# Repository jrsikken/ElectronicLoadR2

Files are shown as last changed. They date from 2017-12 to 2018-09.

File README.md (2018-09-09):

# Hardware of Jasper's Electronic Load R2
This is a Arduino compatible Electronic Load. It is intended for testing DC power supplies, solar panels and batteries. 
I am selling on Tindie https://www.tindie.com/products/jaspersikken/jaspers-electronic-load-r2/
Technical details are also found there.


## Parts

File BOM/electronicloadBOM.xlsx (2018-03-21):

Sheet: electronicloadBOM
Qty | Value | Package | Parts | Description | TOLERANCE | MF | MPN | Ebay
3 | 0.3R | R2512 | R12, R14, R15 | Resistor | 1% |  |  | http://www.ebay.com/itm/100PCS-2512-6432-1W-0-3-ohm-R300-0-3R-1-SMD-resistors/291647639892
1 | 100k | R0603 | R11 | RESISTOR, European symbol | 1% |  |  | http://www.ebay.com/itm/200Pcs-0603-SMD-Resistor-Resistors-1K-910K-Ohm-Ω-1-High-Quality-Free-Shipping/192101507976
3 | 100n | C0603 | C2, C4, C7 | CAPACITOR, European symbol | 10% |  |  | http://www.ebay.com/itm/100PCS-0603-1608-100n-100nF-104K-10-50V-X7R-SMD-capacitor-MLCC/391284797144
3 | 150R | R0603 | R3, R4, R13 | RESISTOR, European symbol | 1% |  |  | http://www.ebay.com/itm/200PCS-150R-150-ohm-Ω-1-1-10W-SMD-Chip-Resistor-0603-1-6mm-0-8mm/231949532343
1 | 1k8 | R0603 | R1 | RESISTOR, European symbol | 1% |  |  | http://www.ebay.com/itm/100pcs-0603-SMD-Resistor-1-8K-ohm-1K8-Tol-5-RoHS-1-10W/291817476969
4 | 1u | C0603 | C1, C3, C5, C6 | CAPACITOR, European symbol | 10% |  |  | http://www.ebay.com/itm/100PCS-1uF-105K-10-16V-X7R-0603-1608-SMD-capacitor-MLCC-1-6mm-0-8mm/232352831873
4 | 20k | R0603 | R2, R5, R8, R10 | RESISTOR, European symbol | 1% |  |  | http://www.ebay.com/itm/200Pcs-0603-SMD-Resistor-Resistors-1K-910K-Ohm-Ω-1-High-Quality-Free-Shipping/192101507976
1 | 22n | C0603 | C8 | CAPACITOR, European symbol | 10% |  |  | http://www.ebay.com/itm/100PCS-22nF-223-10-50V-X7R-0603-1608-SMD-capacitor-MLCC/232244234398
1 | 2k2 | R0603 | R9 | RESISTOR, European symbol | 1% |  |  | http://www.ebay.com/itm/200Pcs-0603-SMD-Resistor-Resistors-1K-910K-Ohm-Ω-1-High-Quality-Free-Shipping/192101507976
3 | 3k6 | R0603 | R6, R7, R16 | RESISTOR, European symbol | 1% |  |  | http://www.ebay.com/itm/200Pcs-0603-SMD-Resistor-Resistors-1K-910K-Ohm-Ω-1-High-Quality-Free-Shipping/192101507976
1 | MCP6074-E/SL | SO14 | U2 | Op Amp |  | Microchip | MCP6074-E/SL
1 | ARDUINO_BLUEPILL | ARDUINO_BLUEPILL | U1 | PCB assembly |  |  |  | http://www.ebay.com/itm/10PCS-STM32F103C8T6-ARM-STM32-Minimum-System-Development-Board-Module-Arduino/171907093814
1 | KF128-2P | KF128-2P | X1 | KF128-2P (5.08 mm) TERMINAL BLOCK |  |  |  | http://www.ebay.com/itm/20pcs-2Pin-Plug-in-Terminal-Block-DG128-Screw-KF128-2P-Pitch-5-08MM-300V-10A/391527936166
1 | BTS133BKSA1 | TO220BV | Q1 | Smart low side power switch |  | Infineon | BTS133BKSA1 | There's are fake ones on ebay. Please buy from Digikey, Mouser, Farnell etc.
1 | AK-122 | SK129-HOLE | KK1 | Aluminum Heatsink Ak-122 H=45mm 42x25x45mm Color=Natural TO-TO-220 |  |  |  | http://www.ebay.com/itm/20pc-Aluminum-Heatsink-Ak-122-H-45mm-Size-42x25x45mm-Color-Natural-TO-3P-TO-220/131284780674
1 | 530002B02500G | SK129-HOLE | KK1-alternative | Aluminum Heatsink H=63.5mm 42x25x63mm Black TO-TO-220 |  | AAVID THERMALLOY | 530002B02500G | http://nl.farnell.com/aavid-thermalloy/530002b02500g/heat-sink-2-6k-w-to-220/dp/2295719
2 | 20p female header |  |  | 2.54mm Pitch 1X20 Pin Female Single Row Straight Header Connector |  |  |  | http://www.ebay.com/itm/20pcs-2-54mm-Pitch-1X-20-Pin-Female-Single-Row-Straight-Header-Connector-PCB-DIY/132035408776
4 | rubber feet | 8 x 2.5 mm |  | Adhesive Silicone Feet Bumpers |  |  |  | http://www.ebay.com/itm/100PCS-Self-Adhesive-Rubber-Feet-Clear-Semicircle-Bumpers-Door-Buffer-Pad/361356150996
1 | heat sink mounting kit |  |  | TO-220 Heatsink Mounting Insulator Kit |  |  |  | http://www.ebay.com/itm/20-sets-TO-220-Heatsink-Mounting-Insulator-Kits/190888986454
1 | CE sticker |  |  | CE Adhesive Sticker |  |  |  | http://www.ebay.com/itm/3-Sheets-CE-Certificated-Label-Stickers-Adhesive-Sticker-Markers-Home-Appliance/172533333629
1 | PCB R2 |  |  | PCB Jasper's Electronic Load R2

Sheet: Revision
Revision | Changes
2.00 | The first released version
2.01 | Changed C5, C7, C6
2.02 | Replaced opamp LMV324 with MCP6004-I/SL
2.03 | Replaced mosfet with BTS133BKSA1
2.1 | Replaced opamp MCP4006 with MCP6074-E/SL
2.2 | Added option for 31W heat sink

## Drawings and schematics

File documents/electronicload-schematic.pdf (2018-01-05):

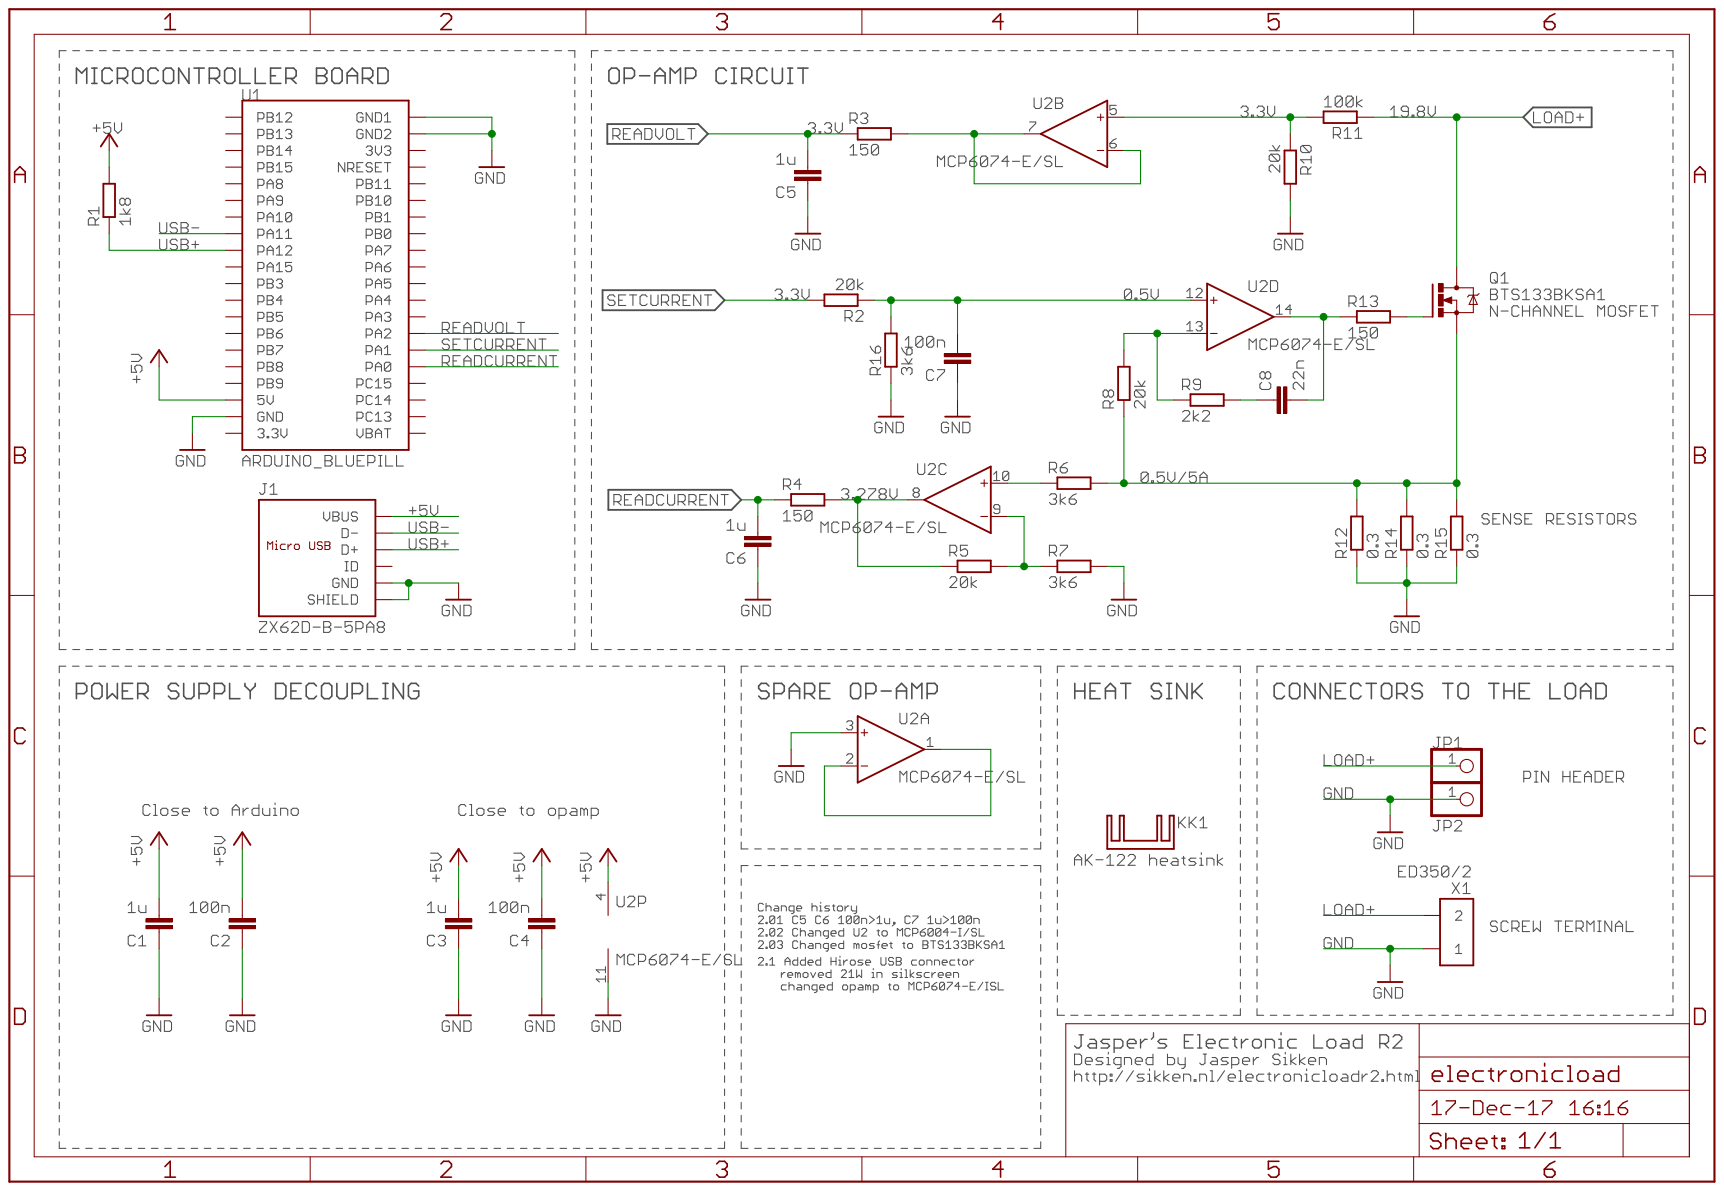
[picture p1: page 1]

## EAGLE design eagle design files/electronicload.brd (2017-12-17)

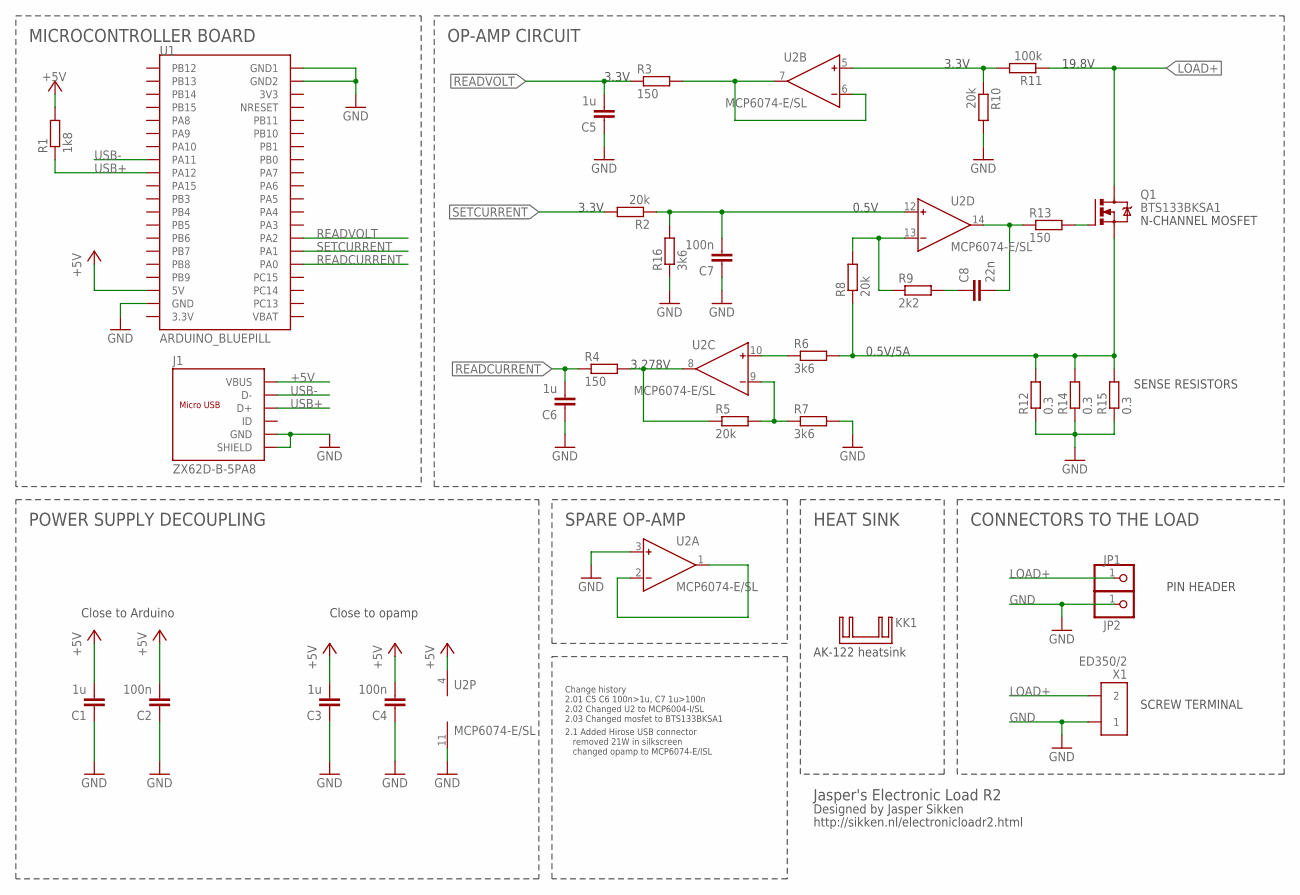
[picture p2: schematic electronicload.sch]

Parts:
C1, C3: 1u; C0603K; TOLERANCE 10%; VOLTAGE 16V; DIGIKEY 311-1444-1-ND
C2, C4: 100n; C0603K; TOLERANCE 10%; VOLTAGE 50V; DIGIKEY 445-7456-1-ND
C5, C6: 1u; C0603K; TOLERANCE 10%; VOLTAGE 50V; DIGIKEY 445-7456-1-ND
C7: 100n; C0603K; TOLERANCE 10%; VOLTAGE 50V; DIGIKEY 445-12511-1-ND
C8: 22n; C0603K; TOLERANCE 10%; VOLTAGE 25V; DIGIKEY 445-12490-1-ND
J1: ZX62D-B-5PA8; MICRO-USB5+6P-SMD-0.65-AB
JP1, JP2: PINHD-1X1; 1X01
KK1: SK129; SK129-HOLE
Q1: BTS133BKSA1; TO220BV; DIGIKEY BTS133BKSA1-ND
R1: 1k8; R0603; DIGIKEY RMCF0603JT18K0CT-ND
R2, R8: 20k; R0603; DIGIKEY RMCF0603JT18K0CT-ND
R3, R4, R13: 150; R0603; DIGIKEY RMCF0603JT150RCT-ND
R5: 20k; R0603; DIGIKEY RMCF0603JT180KCT-ND
R6, R7: 3k6; R0603; DIGIKEY RMCF0603JT20K0CT-ND
R9: 2k2; R0603; DIGIKEY RMCF0603JT2K20CT-ND
R10: 20k; R0603; DIGIKEY RMCF0603JT20K0CT-ND
R11: 100k; R0603; DIGIKEY RMCF0603JT100KCT-ND
R12, R14, R15: 0.3; R2512
R16: 3k6; R0603; DIGIKEY RMCF0603JT18K0CT-ND
U1: ARDUINO_BLUEPILL
U2: MCP6074-E/SL; SO14
X1: ED350/2

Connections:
+5V: C1.2, C2.2, C3.2, C4.2, J1.1 (VBUS), R1.2, U1.P$37 (5V), U2.4 (V+)
GATE: Q1.G, R13.2
GND: C1.1, C2.1, C3.1, C4.1, C5.1, C6.1, C7.1, J1.5 (GND), J1.P1 (SHIELD), J1.P2 (SHIELD), J1.P3 (SHIELD), J1.P4 (SHIELD), J1.P5 (SHIELD), J1.P6 (SHIELD), JP2.1, R7.2, R10.2, R12.1, R14.1, R15.1, R16.1, U1.P$18 (GND2), U1.P$19 (GND1), U1.P$38 (GND), U2.3 (IN+), U2.11 (V-), X1.P$1 (1)
LOAD+: JP1.1, Q1.D, R11.1, X1.P$2 (2)
unnamed: C8.2, R13.1, U2.14 (OUT)
unnamed: R3.2, U2.6 (IN-), U2.7 (OUT)
unnamed: R6.1, U2.10 (IN+)
unnamed: R8.2, R9.1, U2.13 (IN-)
unnamed: R10.1, R11.2, U2.5 (IN+)
unnamed: C7.2, R2.1, R16.2, U2.12 (IN+)
unnamed: R5.2, R7.1, U2.9 (IN-)
unnamed: R4.2, R5.1, U2.8 (OUT)
unnamed: C8.1, R9.2
unnamed: U2.1 (OUT), U2.2 (IN-)
READCURRENT: C6.2, R4.1, U1.P$4 (PA0)
READVOLT: C5.2, R3.1, U1.P$6 (PA2)
SENSE: Q1.S, R6.2, R8.1, R12.2, R14.2, R15.2
SETCURRENT: R2.2, U1.P$5 (PA1)
USB+: J1.3 (D+), R1.1, U1.P$28 (PA12)
USB-: J1.2 (D-), U1.P$27 (PA11)

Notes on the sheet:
POWER SUPPLY DECOUPLING
PIN HEADER
SCREW TERMINAL
SENSE RESISTORS
N-CHANNEL MOSFET
3.3V
19.8V
0.5V
0.5V/5A
3.278V
Designed by Jasper Sikken
http://sikken.nl/electronicloadr2.html
Close to Arduino
Close to opamp
HEAT SINK
SPARE OP-AMP
CONNECTORS TO THE LOAD
MICROCONTROLLER BOARD
OP-AMP CIRCUIT
AK-122 heatsink
Jasper's Electronic Load R2
Change history 2.01 C5 C6 100n>1u, C7 1u>100n 2.02 Changed U2 to MCP6004-I/SL 2.03 Changed mosfet to BTS133BKSA1
2.1 Added Hirose USB connector removed 21W in silkscreen changed opamp to MCP6074-E/ISL

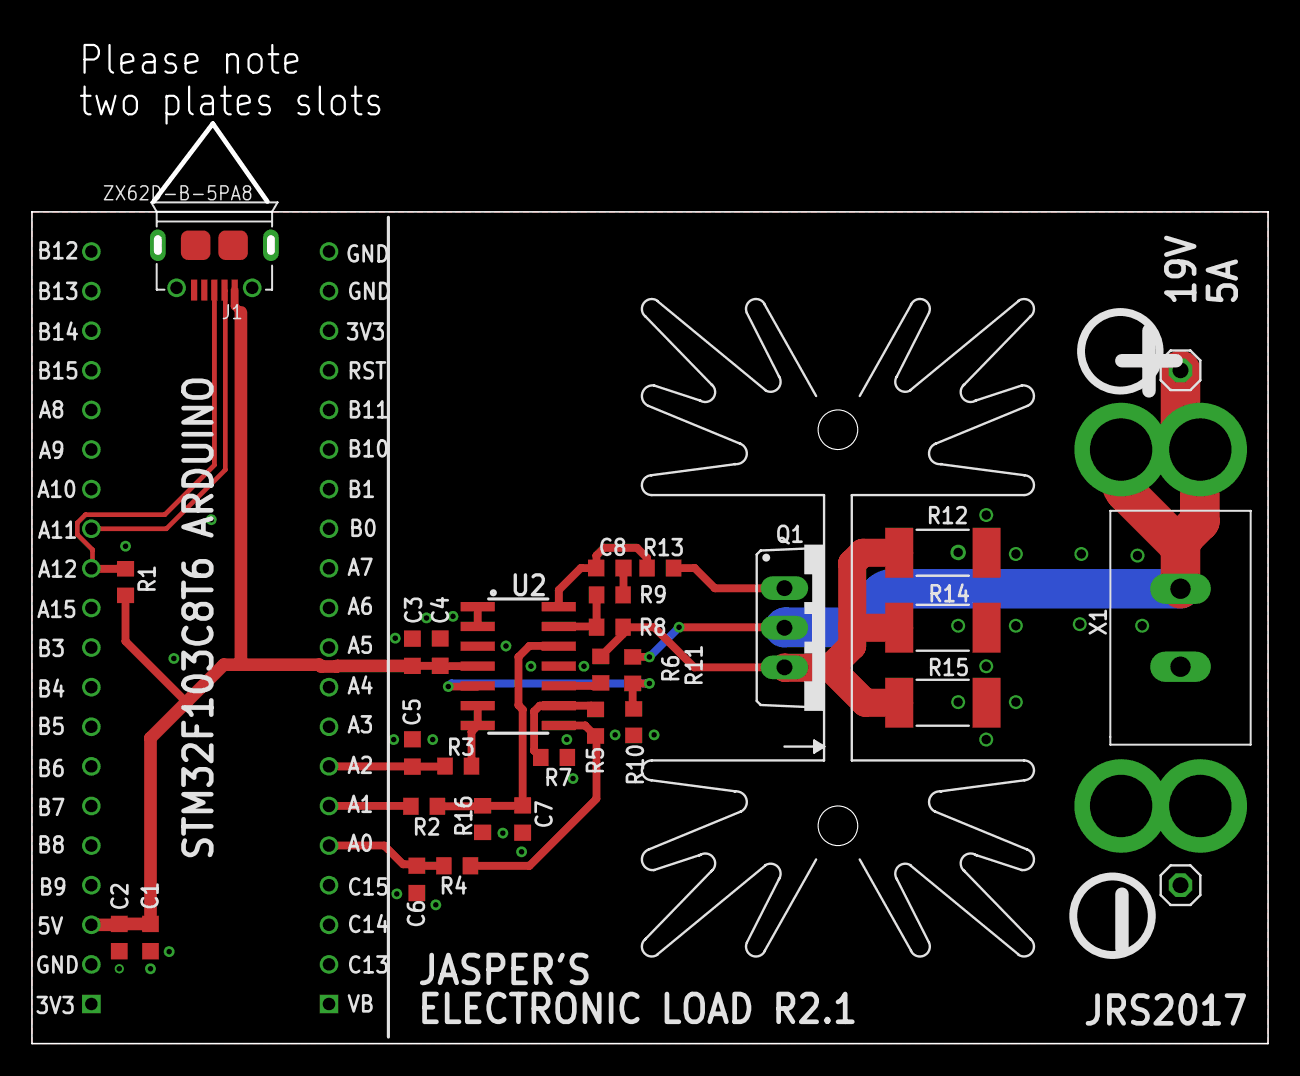
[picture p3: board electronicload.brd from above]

Board: 2 copper layers, 79.3 x 53.3 mm, 32 parts (0 on the bottom side), 20 nets.

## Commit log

2017-10-17 Added eagle design files, and schematic in pdf
    [electronicload.brd, electronicload.sch]
2017-10-17 added gerber and BOM
    [electronicloadBOM.xlsx]
2017-10-22 R2.01 Changed capacitor values.
    [electronicload.brd, electronicload.sch]
2017-10-22 R2.01 changed C5, C6, C7
    [electronicloadBOM.xlsx]
2017-11-01 R2.02 changed opamp to MCP6004-I/SL
    [electronicloadBOM.xlsx]
2017-11-01 Add location where I sell the device
2017-11-10 2.03 Changed mosfet to the much more robust BTS133
    [electronicload.brd, electronicload.sch, electronicloadBOM.xlsx]
2017-12-15 changed opamp from MCP6004 to MCP6074 (much lower input voltage offset)
    [electronicloadBOM.xlsx]
2017-12-17 R2.1 New PCB design, added USB connector, changed mosfet from MCP6004 to MCP6074-E/SL
    [electronicload.brd, electronicload.sch, electronicloadBOM.xlsx]
2018-01-05 added schematic R2.1 in pdf format
2018-03-21 BOM R2.1.1 Added extra large heat sink (31W) to the BOM
    [electronicloadBOM.xlsx]
